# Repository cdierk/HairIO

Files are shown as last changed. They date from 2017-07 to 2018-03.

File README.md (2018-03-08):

# HairIO: Human Hair as interactive Material
Shared Repository for HairIO: Human Hair as interactive Material

# Hardware details
- Microcontroller: Arduino Nano, ordered from AliExpress. Requires [these drivers.](https://github.com/MPParsley/ch340g-ch34g-ch34x-mac-os-x-driver/)
- 

# Circuit diagram for SFCS from Disney's Touche project, as shared by Illutron
// Illutron take on Disney style capacitive touch sensor using only passives and Arduino
// Dzl 2012

```
//                              10n
// PIN 9 --[10k]-+-----10mH---+--||-- OBJECT
//               |            |
//              3.3k          |
//               |            V 1N4148 diode
//              GND           |
//                            |
//Analog 0 ---+------+--------+
//            |      |
//          100pf   1MOmhm
//            |      |
//           GND    GND
```

# Arduino code
- [mux_4052](https://github.com/cdierk/EEPP/tree/master/4052_mux_test_code) - newer version of mux that only requires two pins to select between 4 inputs. Uses [Disney's Touche that was ported to Arduino.](http://www.instructables.com/id/Touche-for-Arduino-Advanced-touch-sensing/)
- [touch_sensing_bluefruit_v2](https://github.com/cdierk/EEPP/tree/master/touch_sensing_bluefruit_v2) - Currently believe this is what's in the bluetooth-enabled demo box w/ brown hair that can actuate and communicate over bluetooth.

# Arduino pinout notes
## For mux_4052 code
- pinMode(9, OUTPUT);       //-Signal generator pin  // digital PWM
- pinMode(8, OUTPUT);       //-Sync (test) pin       // digital
- pinMode(LED, OUTPUT);
- pinMode(muxApin, OUTPUT);                          // pin 6, digital PWM
- pinMode(muxBpin, OUTPUT);                          // pin 5, digital PWM
- pinMode(braidOutput, OUTPUT);                      // pin 2, digital
- // Also uses Analog 0 later.
  
  Total: 5 digital pins, 1 analog pin.
  
## For touch_sensing_bluefruit_v2 code
// cap-sense pin
- pinMode(9, OUTPUT);       //-Signal generator pin
- pinMode(8, OUTPUT);       //-Sync (test) pin
- pinMode(drive, OUTPUT);

 //bluetooth:
- BLUEFRUIT_UART_MODE_PIN,
- BLUEFRUIT_UART_CTS_PIN, 
- BLUEFRUIT_UART_RTS_PIN

# Resources
[Instructable for Disney Touche's SFCS](http://www.instructables.com/id/Touche-for-Arduino-Advanced-touch-sensing/)

# Datasheets and Circuit Info
- [4052 mux from TI](http://www.ti.com/lit/ds/symlink/cd4051b.pdf)
- [Arduino Nano CAD files](https://forum.arduino.cc/index.php?topic=373897.0)
- [SPDT Slide switch datasheet from DigiKey](https://media.digikey.com/pdf/Data%20Sheets/C&K/SS-12D07-VG_GA_PA.pdf)
  - For Eagle, use a 1x3-pin header from Pinhead since they are also 2mm apart.

# demo
- Multiple braids w/ BLE
- Single braid w/ BLE

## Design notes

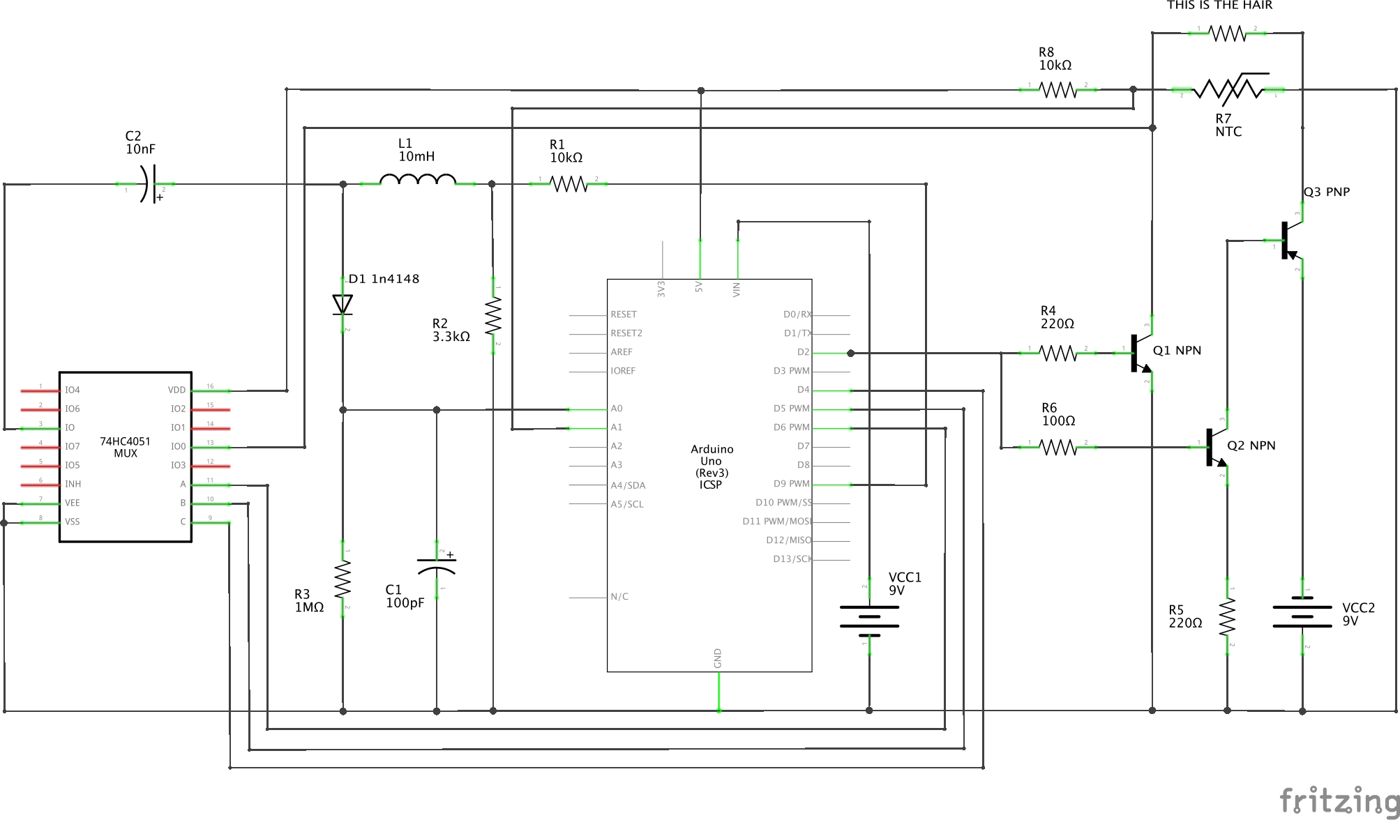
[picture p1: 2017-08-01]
hair_whole_system_schem.png

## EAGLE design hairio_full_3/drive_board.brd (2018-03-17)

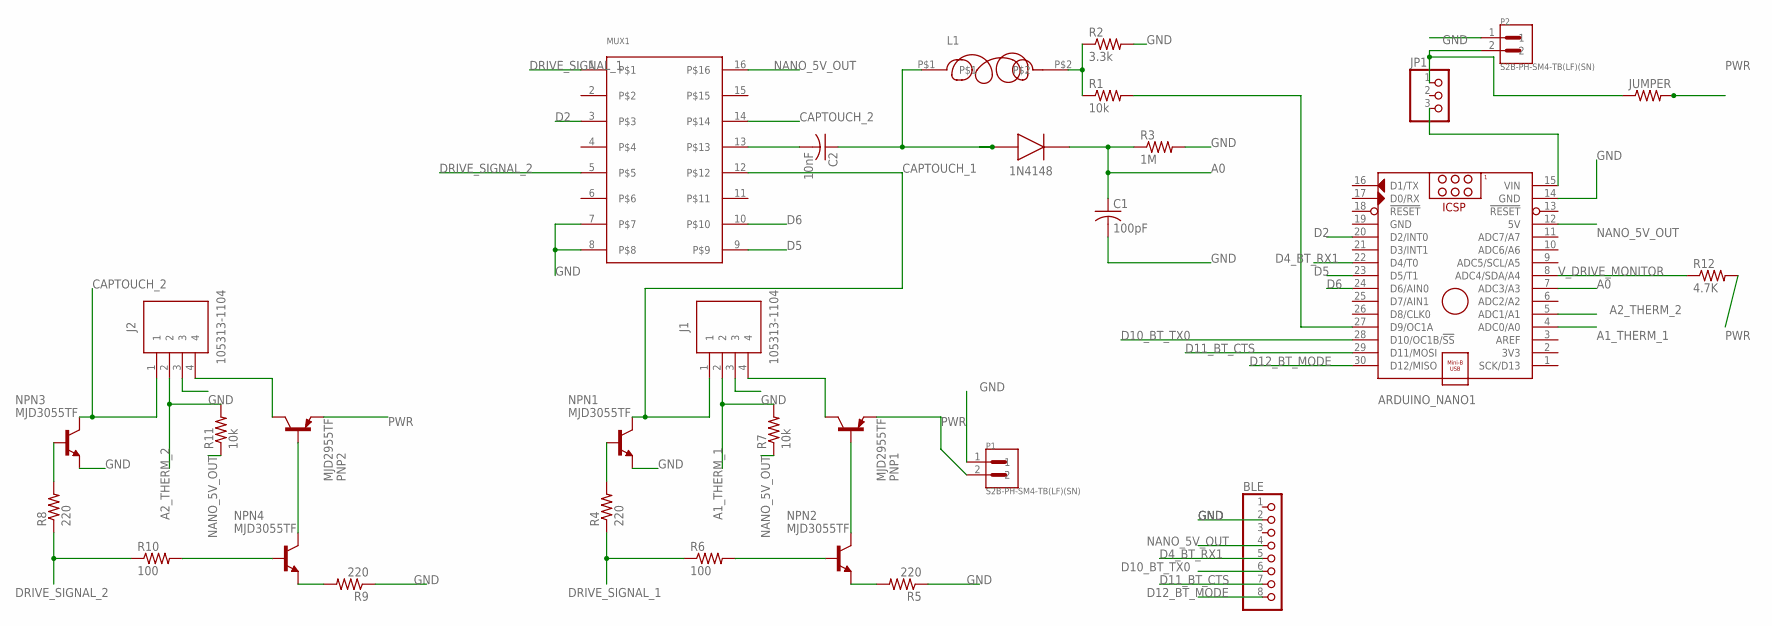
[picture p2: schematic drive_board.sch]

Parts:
1N4148: 1N5819HW-7-F; SOD3716X145N
ARDUINO_NANO1: ARDUINO_NANO
BLE: PINHD-1X8; 1X08
C1: 100pF; C0805
C2: 10nF; C0805
J1, J2: 105313-1104
JP1: PINHD-1X3; 1X03
JUMPER: R-US_R0805; R0805
L1: SRE6603
MUX1: HAIRIO_MUX; SO16
NPN1, NPN2, NPN3, NPN4: MJD3055TF; DPAK
P1, P2: S2B-PH-SM4-TB(LF)(SN); JST_S2B-PH-SM4-TB(LF)(SN)
PNP1, PNP2: MJD2955TF; DPAK
R1, R7, R11: 10k; R0805
R2: 3.3k; R0805
R3: 1M; R0805
R4, R5, R8, R9: 220; R0805
R6, R10: 100; R0805
R12: 4.7K; R0805

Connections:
A0: 1N4148.1 (K), ARDUINO_NANO1.7 (ADC3/A3), C1.1, R3.1
A1_THERM_1: ARDUINO_NANO1.4 (ADC0/A0), J1.2, R7.2
A2_THERM_2: ARDUINO_NANO1.5 (ADC1/A1), J2.2, R11.2
CAPTOUCH_1: J1.1, MUX1.12, NPN1.4 (C)
CAPTOUCH_2: J2.1, MUX1.14, NPN3.4 (C)
D2: ARDUINO_NANO1.20 (D2/INT0), MUX1.3
D4_BT_RX1: ARDUINO_NANO1.22 (D4/T0), BLE.5
D5: ARDUINO_NANO1.23 (D5/T1), MUX1.9
D6: ARDUINO_NANO1.24 (D6/AIN0), MUX1.10
D10_BT_TX0: ARDUINO_NANO1.28 (D10/OC1B/!SS), BLE.6
D11_BT_CTS: ARDUINO_NANO1.29 (D11/MOSI), BLE.7
D12_BT_MODE: ARDUINO_NANO1.30 (D12/MISO), BLE.8
DRIVE_SIGNAL_1: MUX1.1, R4.1, R6.1
DRIVE_SIGNAL_2: MUX1.5, R8.1, R10.1
GND: ARDUINO_NANO1.14 (GND), ARDUINO_NANO1.19 (GND), BLE.2, C1.2, J1.3, J2.3, MUX1.7, MUX1.8, NPN1.3 (E), NPN3.3 (E), P1.1, P2.1, R2.2, R3.2, R5.1, R9.1
unnamed: NPN2.1 (B), R6.2
unnamed: NPN2.3 (E), R5.2
unnamed: NPN4.1 (B), R10.2
unnamed: NPN2.4 (C), PNP1.1 (B)
unnamed: NPN1.1 (B), R4.2
unnamed: C2.2, MUX1.13
unnamed: 1N4148.2 (A), C2.1, L1.P$1
unnamed: J1.4, PNP1.4 (C)
unnamed: ARDUINO_NANO1.27 (D9/OC1A), R1.2
unnamed: L1.P$2, R1.1, R2.1
unnamed: NPN4.3 (E), R9.2
unnamed: ARDUINO_NANO1.15 (VIN), JP1.3
unnamed: NPN4.4 (C), PNP2.1 (B)
unnamed: NPN3.1 (B), R8.2
unnamed: J2.4, PNP2.4 (C)
unnamed: JP1.1, JUMPER.1, P2.2
NANO_5V_OUT: ARDUINO_NANO1.12 (5V), BLE.4, MUX1.16, R7.1, R11.1
PWR: JUMPER.2, P1.2, PNP1.3 (E), PNP2.3 (E), R12.2
V_DRIVE_MONITOR: ARDUINO_NANO1.8 (ADC4/SDA/A4), R12.1

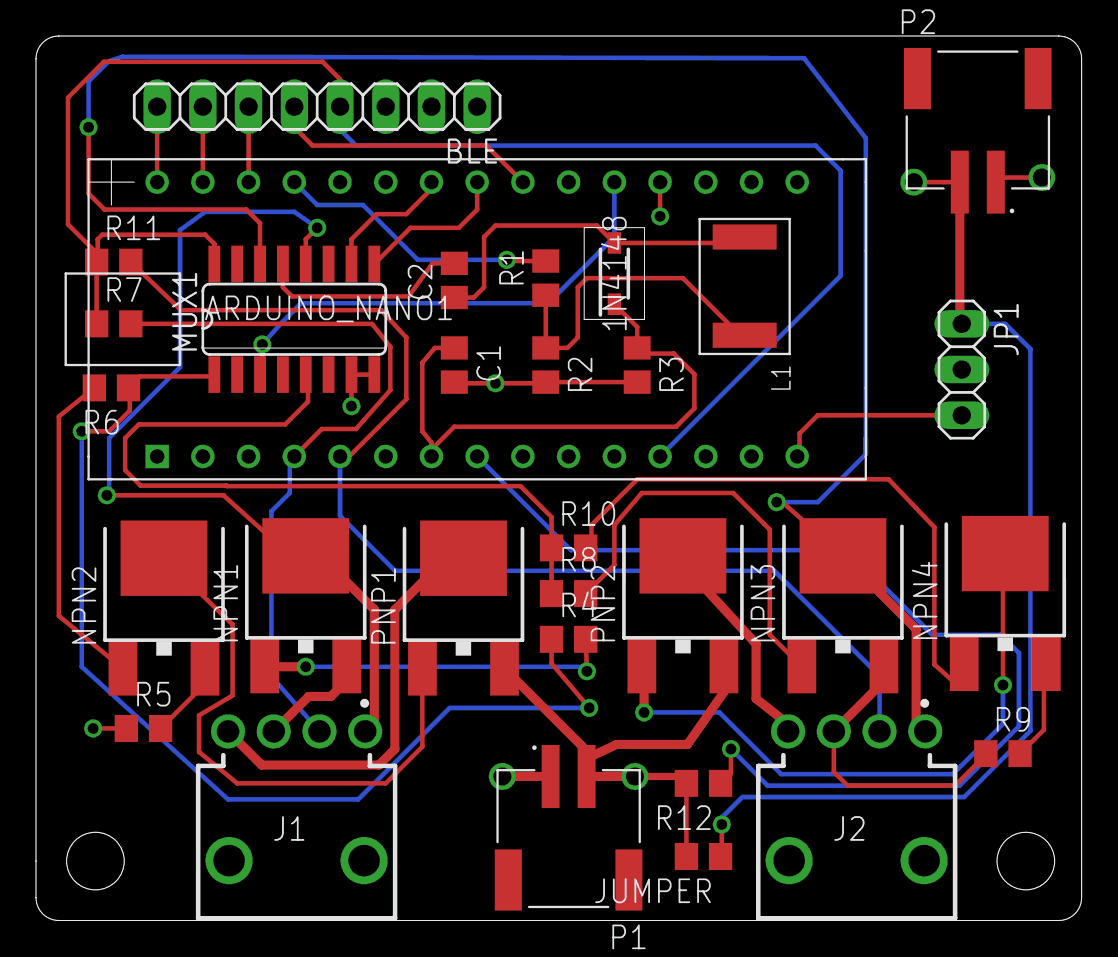
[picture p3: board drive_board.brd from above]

Board: 2 copper layers, 58.1 x 49.1 mm, 31 parts (0 on the bottom side), 34 nets.

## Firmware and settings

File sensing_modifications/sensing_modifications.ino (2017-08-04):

//****************************************************************************************
// Adapted from https://github.com/Illutron/AdvancedTouchSensing
// Moves the gesture analysis from Processing to run entirely on Arduino, with fixed thresholds
// July 21 2017
//****************************************************************************************



//****************************************************************************************
// Illutron take on Disney style capacitive touch sensor using only passives and Arduino
// Dzl 2012
//****************************************************************************************


//                              10n
// PIN 9 --[10k]-+-----10mH---+--||-- OBJECT
//               |            |
//              3.3k          |
//               |            V 1N4148 diode
//              GND           |
//                            |
//Analog 0 ---+------+--------+
//            |      |
//          100pf   1MOmhm
//            |      |
//           GND    GND

//EDIT THIS ONE YAY!
float tempThreshhold = 32.0;

#define SET(x,y) (x |=(1<<y))        //-Bit set/clear macros
#define CLR(x,y) (x &= (~(1<<y)))           // |
#define CHK(x,y) (x & (1<<y))               // |
#define TOG(x,y) (x^=(1<<y))                //-+

#define LED 13 // LED for serial-less debugging.

#define N 160  //How many frequencies

//mux
#define muxApin 6
#define muxBpin 5
#define muxCpin 4
int previousMillis = 0;
#define switchInterval 100

unsigned int currentMillis = 0;

#define braid0 2    //pin for braid 0 output
#define braid1 3    //pin for braid 1 output
#define braid2 7    //pin for braid 2 output

//thermistor specific stuff
#define therm0 A1   //pin for braid 0 thermistor
#define therm1 A2   //pin for braid 1 thermistor
#define therm2 A3   //pin for braid 2 thermistor
//resistance at 25 degrees C
#define THERMISTORNOMINAL 10000
// temperature for nominal resistance
#define TEMPERATURENOMINAL 25
//how many samples to take before averaging the temperature
#define NUMSAMPLES 5
//beta coefficient of the thermistor
#define BCOEFFICIENT 3950
//value of 'other' resistor
#define SERIESRESISTOR 10000


int on_average = 0;
int off_average = 0;

int on_average_count = 0;
int off_average_count = 0;

int currentBraid = braid0;
int currentTherm = therm0;

uint16_t samples[NUMSAMPLES];

bool driving = false; //true if currently driving one of the braids

//Gesture sensing variables
float results[N];            //-Filtered result buffer
float freq[N];            //-Filtered result buffer
int sizeOfArray = N;

//Gesture processing variables
float gesturePoints[2][2];
float gestureDist[2];
String names[2] = {"nothing", "touch"};

int curGesture = 0;
int lastGesture = 0;

void setGestureThresholds() {
  gesturePoints[0][0] = 0;
  gesturePoints[0][1] = 350;

  gesturePoints[1][0] = 0;
  gesturePoints[1][1] = 310;

  on_average = gesturePoints[1][1];
  off_average = gesturePoints[0][1];
  
  on_average_count = 1;
  off_average_count = 1;

}


void setup()
{

  Serial.begin(115200);
  Serial.println("STart");
  
  TCCR1A = 0b10000010;      //-Set up frequency generator
  TCCR1B = 0b00011001;      //-+
  ICR1 = 110;
  OCR1A = 55;

  pinMode(9, OUTPUT);       //-Signal generator pin
  pinMode(8, OUTPUT);       //-Sync (test) pin
  pinMode(LED, OUTPUT);
  pinMode(muxApin, OUTPUT);
  pinMode(muxBpin, OUTPUT);
  pinMode(muxCpin, OUTPUT);
  pinMode(braid0, OUTPUT);
  pinMode(braid1, OUTPUT);
  pinMode(braid2, OUTPUT);
  pinMode(10, INPUT);         //config
  pinMode(12, INPUT);         //config
  pinMode(13, OUTPUT);       //LED

  // initialize results array to all zeros
  memset(results,0,sizeof(results)); 

  driving= false;

    digitalWrite(muxApin, 0);
    digitalWrite(muxBpin, 0);
    digitalWrite(muxCpin, 0);

  setGestureThresholds();

}




void processGesture() {
  //input found on current braid
  if ((curGesture == 1) && (currentMillis > 5000)){
//    digitalWrite(currentBraid, HIGH);
    digitalWrite(13, HIGH);
//    driving = true;
  } else {
     digitalWrite(13, LOW);
  }
}

//adapted from http://forum.arduino.cc/index.php?topic=41999.0
float getMaxFromArray(float* array, int size) {
  float max = array[0];
  for (int i = 1; i < size; i++) {
    if (max < array[i]) {
      max = array[i];
    }
  }
  return max;
}

int getMaxIndexFromArray(float* array, int size) {
  float max = array[0];
  int index = 0;
  for (int i = 1; i < size; i++) {
    if (max < array[i]) {
      max = array[i];
      index = i;
    }
  }
  return index;
}

//assumes no negative values for time or voltage
float dist(float x1, float y1, float x2, float y2) {
  float xmax = max(x1, x2);
  float ymax = max(y1, y2);

  float w;
  if (x1 > x2) {
    w = x1 - x2;
  } else {
    w = x2 - x1;
  }
  float h;
  if (y1 > y2) {
    h = y1 - y2;
  } else {
    h = y2 - y1;
  }

  return sqrt(h * h + w * w);
}

void analyzeInput(float timeArr[], float voltageArr[]) {

  /* ====================================================================
    Gesture compare
    ====================================================================  */
  
    int currentMax = 0;
    float currentMaxValue = -1;
    for (int i = 0; i < 2; i++)
    {
      //calculate individual dist
      gestureDist[i] = dist(getMaxFromArray(timeArr, N), getMaxFromArray(voltageArr, N), gesturePoints[i][0], gesturePoints[i][1]);
  
      if (gestureDist[i] < currentMaxValue || i == 0)
      {
        currentMax = i;
        currentMaxValue =  gestureDist[i];
      }
    }
  
    int type = currentMax;
    lastGesture = curGesture;
    curGesture = type;

}

void update_thresholds(float freq[], float volts[], char type) {
    Serial.println("old threshold:");
    Serial.println(type);
    Serial.println(gesturePoints[0][0]);
    Serial.println(gesturePoints[0][1]);
    Serial.println(gesturePoints[1][0]);
    Serial.println(gesturePoints[1][1]);

    float on_average = 0;
    float off_average = 0;
    float on_freq = 0;
    float off_freq = 0;

    for (int i = 0; i < 100; i++) {
              unsigned int d;
            
              int counter = 0;
              for (unsigned int d = 0; d < N; d++) {
                int v = analogRead(0);  //-Read response signal
                CLR(TCCR1B, 0);         //-Stop generator
                TCNT1 = 0;              //-Reload new frequency
                ICR1 = d;               // |
                OCR1A = d / 2;          //-+
                SET(TCCR1B, 0);         //-Restart generator
            
                results[d] = results[d] * 0.5 + (float)(v) * 0.5; //Filter results
                   
                freq[d] = d;
            
                //   plot(v,0);              //-Display
                //   plot(results[d],1);
                 delayMicroseconds(10);
              }
         if (type == 't') {
           on_average += getMaxFromArray(results, N);
//           on_freq += freq[getMaxIndexFromArray(results, N)];
         } else if (type == 'n'){
           off_average = off_average + ( getMaxFromArray(results, N) ) / off_average_count;
//           off_freq += freq[getMaxIndexFromArray(results, N);

         }
    }

    if (type == 't') {
      on_average = on_average / 100;
      on_freq = on_freq / 100;
      gesturePoints[1][0] = on_freq;
      gesturePoints[1][1] = on_average;
    } else if (type == 'n') {
      off_average = off_average/100;
      off_freq = off_freq/100;

      gesturePoints[0][0] = off_freq;
      gesturePoints[0][1] = off_average;
    }

    Serial.println("new threshold:");
    Serial.println(gesturePoints[0][0]);
    Serial.println(gesturePoints[0][1]);
    Serial.println(gesturePoints[1][0]);
    Serial.println(gesturePoints[1][1]);
    
//    if (type == 't') {

//      on_average = on_average + ( getMaxFromArray(volts, N) ) / on_average_count;
//      on_average_count = on_average_count + 1;
//            
//      gesturePoints[1][0] = getMaxIndexFromArray(volts, N);
//      gesturePoints[1][1] = on_average;
//    } else if (type == 'n'){
//
//      off_average = off_average + ( getMaxFromArray(volts, N) ) / off_average_count;
//      off_average_count = off_average_count + 1;
//
//      gesturePoints[0][0] = getMaxIndexFromArray(volts, N);
//      gesturePoints[0][1] = off_average;
//    }  
}

void loop()
{
              unsigned int d;
            
              int counter = 0;
              for (unsigned int d = 0; d < N; d++) {
                int v = analogRead(0);  //-Read response signal
                CLR(TCCR1B, 0);         //-Stop generator
                TCNT1 = 0;              //-Reload new frequency
                ICR1 = d;               // |
                OCR1A = d / 2;          //-+
                SET(TCCR1B, 0);         //-Restart generator
            
                results[d] = results[d] * 0.5 + (float)(v) * 0.5; //Filter results
                   
                freq[d] = d;
            
                //   plot(v,0);              //-Display
                //   plot(results[d],1);
                // delayMicroseconds(1);
              }


  //this would send the data to processing
//  PlottArray(1,freq,results);

  // instead of sending to processing, do the work here

  
  analyzeInput(freq, results);


  processGesture();

  if (digitalRead(12) == HIGH) {
    update_thresholds(freq, results, 't'); 
  } else if (digitalRead(10) == HIGH) {
    update_thresholds(freq, results, 'n');
  }

    //mux -- cycles through braids looking for input
    currentMillis = millis();
                                            
                                        //    //doesn't cycle if powering one of the braids
                                        //    if((currentMillis - previousMillis > switchInterval) && (driving == false)){
                                        //      // save the last time you switched 
                                        //      previousMillis = currentMillis;   
                                        //
                                              if (currentBraid == braid0){               //mux pin0 is attached to same braid as Arduino pin2
                                                digitalWrite(muxApin, 0);
                                                digitalWrite(muxBpin, 0);
                                                digitalWrite(muxCpin, 0);
                                                currentBraid = braid0;  
                                              }
                                               //UNCOMMENT THIS FOR MULTI-BRAID USE!
                                        //      } else if (currentBraid == braid1){        //mux pin1 is attached to same braid as Arduino pin3
                                        //        digitalWrite(muxApin, 1);
                                        //        digitalWrite(muxBpin, 0);
                                        //        digitalWrite(muxCpin, 0);
                                        //        currentBraid = braid0;
                                        //      }
                                        //      } else {        //mux pin2 is attached to same braid as Arduino pin7
                                        //        digitalWrite(muxApin, 0);
                                        //        digitalWrite(muxBpin, 1);
                                        //        digitalWrite(muxCpin, 0);
                                        //        currentBraid = braid0;
                                        //      }
                                        //    }

    
    //only care about thermistor values if we're currently driving
      if (driving == true) {
                                                                                uint8_t i;
                                                                                float average;
                                                                        
                                                                                //take N samples in a row, with a slight delay
                                                                                if (currentBraid == braid0) currentTherm = therm0;
                                                                                else if (currentBraid == braid1) currentTherm = therm1;
                                                                                else if (currentBraid == braid2) currentTherm = therm2;
                                                                                
                                                                                for (i = 0; i < NUMSAMPLES; i++) {
                                                                                  samples[i] = analogRead(currentTherm);
                                                                                  delay(10);
                                                                                }
                                                                        
                                                                                // average all the samples out
                                                                                average = 0;
                                                                                for (i = 0; i < NUMSAMPLES; i++) {
                                                                                  average += samples[i];
                                                                                }
                                                                                average /= NUMSAMPLES;
                                                                        
                                                                                //convert these values to resistance
                                                                                average = 1023 / average - 1;
                                                                                average = SERIESRESISTOR / average;
                                                                        
                                                                                //convert these values to temperature
                                                                                average = average / THERMISTORNOMINAL;
                                                                                average = log(average);
                                                                                average /= BCOEFFICIENT;
                                                                                average += 1.0 / (TEMPERATURENOMINAL + 273.15);
                                                                                average = 1.0 / average;
                                                                                average -= 273.15;
                                                                        
                                                                                //average is now the temperature of the thermistor
                                                                        //        Serial.println(average);
                                                                        
                                                                                if ( average <= 0.0){
                                                                                  digitalWrite(currentBraid, LOW);
                                                                                  driving = false;
                                                                                  delay(5000);
                                                                                  
                                                                                } else if (average >= tempThreshhold){
                                                                        //          Serial.println("here inside kill");
                                                                                  digitalWrite(currentBraid, LOW);
                                                                                  driving = false;
                                                                                }
        
      }

  TOG(PORTB, 0);           //-Toggle pin 8 after each sweep (good for scope)
}

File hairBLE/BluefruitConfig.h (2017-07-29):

// COMMON SETTINGS
// ----------------------------------------------------------------------------------------------
// These settings are used in both SW UART, HW UART and SPI mode
// ----------------------------------------------------------------------------------------------
#define BUFSIZE                        128   // Size of the read buffer for incoming data
#define VERBOSE_MODE                   true  // If set to 'true' enables debug output


// SOFTWARE UART SETTINGS
// ----------------------------------------------------------------------------------------------
// The following macros declare the pins that will be used for 'SW' serial.
// You should use this option if you are connecting the UART Friend to an UNO
// ----------------------------------------------------------------------------------------------
#define BLUEFRUIT_SWUART_RXD_PIN       5    // Required for software serial!
#define BLUEFRUIT_SWUART_TXD_PIN       10   // Required for software serial!
#define BLUEFRUIT_UART_CTS_PIN         11   // Required for software serial!
#define BLUEFRUIT_UART_RTS_PIN         -1   // Optional, set to -1 if unused


// HARDWARE UART SETTINGS
// ----------------------------------------------------------------------------------------------
// The following macros declare the HW serial port you are using. Uncomment
// this line if you are connecting the BLE to Leonardo/Micro or Flora
// ----------------------------------------------------------------------------------------------
#ifdef Serial1    // this makes it not complain on compilation if there's no Serial1
  #define BLUEFRUIT_HWSERIAL_NAME      Serial1
#endif


// SHARED UART SETTINGS
// ----------------------------------------------------------------------------------------------
// The following sets the optional Mode pin, its recommended but not required
// ----------------------------------------------------------------------------------------------
#define BLUEFRUIT_UART_MODE_PIN        12    // Set to -1 if unused


// SHARED SPI SETTINGS
// ----------------------------------------------------------------------------------------------
// The following macros declare the pins to use for HW and SW SPI communication.
// SCK, MISO and MOSI should be connected to the HW SPI pins on the Uno when
// using HW SPI.  This should be used with nRF51822 based Bluefruit LE modules
// that use SPI (Bluefruit LE SPI Friend).
// ----------------------------------------------------------------------------------------------
#define BLUEFRUIT_SPI_CS               8
#define BLUEFRUIT_SPI_IRQ              7
#define BLUEFRUIT_SPI_RST              4    // Optional but recommended, set to -1 if unused

// SOFTWARE SPI SETTINGS
// ----------------------------------------------------------------------------------------------
// The following macros declare the pins to use for SW SPI communication.
// This should be used with nRF51822 based Bluefruit LE modules that use SPI
// (Bluefruit LE SPI Friend).
// ----------------------------------------------------------------------------------------------
#define BLUEFRUIT_SPI_SCK              13
#define BLUEFRUIT_SPI_MISO             12
#define BLUEFRUIT_SPI_MOSI             11

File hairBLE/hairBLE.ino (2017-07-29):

/*********************************************************************
 This is an example for our nRF51822 based Bluefruit LE modules

 Pick one up today in the adafruit shop!

 Adafruit invests time and resources providing this open source code,
 please support Adafruit and open-source hardware by purchasing
 products from Adafruit!

 MIT license, check LICENSE for more information
 All text above, and the splash screen below must be included in
 any redistribution
*********************************************************************/

#include <Arduino.h>
#include <SPI.h>
#if not defined (_VARIANT_ARDUINO_DUE_X_) && not defined (_VARIANT_ARDUINO_ZERO_)
  #include <SoftwareSerial.h>
#endif

#include "Adafruit_BLE.h"
#include "Adafruit_BluefruitLE_UART.h"

#include "BluefruitConfig.h"

/*=========================================================================
    APPLICATION SETTINGS

    FACTORYRESET_ENABLE       Perform a factory reset when running this sketch
   
                              Enabling this will put your Bluefruit LE module
                              in a 'known good' state and clear any config
                              data set in previous sketches or projects, so
                              running this at least once is a good idea.
   
                              When deploying your project, however, you will
                              want to disable factory reset by setting this
                              value to 0.  If you are making changes to your
                              Bluefruit LE device via AT commands, and those
                              changes aren't persisting across resets, this
                              is the reason why.  Factory reset will erase
                              the non-volatile memory where config data is
                              stored, setting it back to factory default
                              values.
       
                              Some sketches that require you to bond to a
                              central device (HID mouse, keyboard, etc.)
                              won't work at all with this feature enabled
                              since the factory reset will clear all of the
                              bonding data stored on the chip, meaning the
                              central device won't be able to reconnect.
    MINIMUM_FIRMWARE_VERSION  Minimum firmware version to have some new features
    MODE_LED_BEHAVIOUR        LED activity, valid options are
                              "DISABLE" or "MODE" or "BLEUART" or
                              "HWUART"  or "SPI"  or "MANUAL"
    -----------------------------------------------------------------------*/
    #define FACTORYRESET_ENABLE         1
    #define MINIMUM_FIRMWARE_VERSION    "0.6.6"
    #define MODE_LED_BEHAVIOUR          "MODE"
/*=========================================================================*/

// Create the bluefruit object in software serial

SoftwareSerial bluefruitSS = SoftwareSerial(BLUEFRUIT_SWUART_TXD_PIN, BLUEFRUIT_SWUART_RXD_PIN);

Adafruit_BluefruitLE_UART ble(bluefruitSS, BLUEFRUIT_UART_MODE_PIN,
                      BLUEFRUIT_UART_CTS_PIN, BLUEFRUIT_UART_RTS_PIN);


// A small helper
void error(const __FlashStringHelper*err) {
  Serial.println(err);
  while (1);
}

/**************************************************************************/
/*!
    @brief  Sets up the HW an the BLE module (this function is called
            automatically on startup)
*/
/**************************************************************************/
void setup(void)
{
  while (!Serial);  // required for Flora & Micro
  delay(500);

  Serial.begin(115200);
  Serial.println(F("Adafruit Bluefruit Command <-> Data Mode Example"));
  Serial.println(F("------------------------------------------------"));

  /* Initialise the module */
  Serial.print(F("Initialising the Bluefruit LE module: "));

  if ( !ble.begin(VERBOSE_MODE) )
  {
    error(F("Couldn't find Bluefruit, make sure it's in CoMmanD mode & check wiring?"));
  }
  Serial.println( F("OK!") );

  if ( FACTORYRESET_ENABLE )
  {
    /* Perform a factory reset to make sure everything is in a known state */
    Serial.println(F("Performing a factory reset: "));
    if ( ! ble.factoryReset() ){
      error(F("Couldn't factory reset"));
    }
  }

  /* Disable command echo from Bluefruit */
  ble.echo(false);

  Serial.println("Requesting Bluefruit info:");
  /* Print Bluefruit information */
  ble.info();

  Serial.println(F("Please use Adafruit Bluefruit LE app to connect in UART mode"));
  Serial.println(F("Then Enter characters to send to Bluefruit"));
  Serial.println();

  ble.verbose(false);  // debug info is a little annoying after this point!

  /* Wait for connection */
  while (! ble.isConnected()) {
      delay(500);
  }

  Serial.println(F("******************************"));

  // LED Activity command is only supported from 0.6.6
  if ( ble.isVersionAtLeast(MINIMUM_FIRMWARE_VERSION) )
  {
    // Change Mode LED Activity
    Serial.println(F("Change LED activity to " MODE_LED_BEHAVIOUR));
    ble.sendCommandCheckOK("AT+HWModeLED=" MODE_LED_BEHAVIOUR);
  }

  // Set module to DATA mode
  Serial.println( F("Switching to DATA mode!") );
  ble.setMode(BLUEFRUIT_MODE_DATA);

  Serial.println(F("******************************"));
}

/**************************************************************************/
/*!
    @brief  Constantly poll for new command or response data
*/
/**************************************************************************/
void loop(void)
{
  // Check for user input
  char n, inputs[BUFSIZE+1];

  if (Serial.available())
  {
    n = Serial.readBytes(inputs, BUFSIZE);
    inputs[n] = 0;
    // Send characters to Bluefruit
    Serial.print("Sending: ");
    Serial.println(inputs);

    // Send input data to host via Bluefruit
    ble.print(inputs);
  }

  // Echo received data
  while ( ble.available() )
  {
    int c = ble.read();

    Serial.print((char)c);

    // Hex output too, helps w/debugging!
    Serial.print(" [0x");
    if (c <= 0xF) Serial.print(F("0"));
    Serial.print(c, HEX);
    Serial.print("] ");
  }
}

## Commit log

2017-07-21 arduino code for touch sensing
2017-07-21 Add first draft of hair curling, color-changing arduino code
2017-07-21 Update for circuit testing - pin 3 goes high and pin 4 goes low.
2017-07-26 Edited Arduino_sensing file to include multiplexer use
    added lines have //mux notes above them. Use with Illutron processing script to visualize. At present, cycles between two capacitive touch inputs at a rate of 5000ms (5 seconds).
2017-07-28 Basic BLE UART from hair circuit to iOS
2017-07-28 Full integrated system (input, output, bluetooth)
    Using mpr121 & bluefruit. Drive circuit is written high from Arduino pin 4.
    Does not include thermistor or multiplexor.
2017-07-29 Tidied up code and switched to LED signal instead of serial print to save bytes
2017-07-29 Updated touch_sensing file with multiplexer code
    Supports 4 braid input with one capacitive touch shield
2017-07-29 Debug messages.
    These confirm that the values passed into the "dist" method
    in arrays don't need to be floats - they are all of the form 158.00
    with no values ever below one. The sqrt value does end up
    having some decimal values: 172.36, but the behavior of the circuit
    seems to be just as good if we use just the int portion of those values
    (dropping the decimal values by storing it in an int instead.)
2017-07-29 Remove some debug prints
2017-07-29 CapSensing Board + Bluefruit
    Currently writing high to pin 13 (Arduino built-in LED) rather than drive circuit. If we change this pin to a pin connected to drive circuit, everything should work!
2017-07-31 multiplexer integration with thermistor, drive, and cap; checks to limit captouch during drive; drive and thermister shut off
2017-08-01 Circuit Diagram excluding BlueTooth
    Includes everything else: cap touch circuit, driver circuit, thermistor, arduino, batteries
    [hair_whole_system.fzz]
2017-08-01 Circuit Diagram excluding BlueTooth
    Includes everything else: cap touch circuit, driver circuit, thermistor, batteries.
    Right now has a resistor as a stand in for the hair and says "this is the hair". Planning to doctor the image in Adobe Illustrator to include an illustrated braid. Also going to outline the different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
2017-08-02 Power test 1 and 2
    temperature and timing for color and shape changes (when they begin and when they finish)
    Power_test_one didn't mark anything past color end and runs for a long time (we were trying to get it to change all the way before realizing that was unfeasible).
2017-08-02 Power Test 3: 1.0A, 1.7V
2017-08-02 Power tests 4 and 5: 3.25V, 2A
2017-08-02 Power Test 6: 3.3V 2A
2017-08-04 demo code
    [power_data.xlsx, power_test_2.csv, power_test_3.csv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]
2018-01-23 rename because arduino IDE didn't like the file starting with a number
    [mux_4052.ino]
2018-02-03 demo board eagle files
    [drive_board.brd, drive_board.sch]
2018-02-06 updated board files
    [drive_board.brd]
2018-02-06 updated net class clearance
    [drive_board.brd, drive_board.sch]
2018-02-08 Updated Capacitive Touch Pin to A5 (from A0)
    also added this as a global variable (capTouchPin) so that we can easily update it in the future
2018-02-08 update board
    [drive_board.brd, drive_board.sch]
2018-02-08 hairio board with no routes between header pins
    [drive_board.brd]
2018-02-08 change via size and shift trace
    [drive_board.brd]
2018-02-08 More tweaks to board
    [drive_board.brd]
2018-02-13 added basic mux
    updated pin numbers in BluefruitConfig.h as well
2018-02-23 added thermistor code and braidx struct; reorganized variables. Untested.
2018-02-23 battery monitoring code, still untested
2018-02-24 working demo code with voltage monitoring for both batteries and thermistor logging
2018-03-02 new board -- the dimensioned version of what got made for demos (with ground plane fix after accidental deletion)
    [drive_board.brd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]
2018-03-08 board layout with dimensions -- modified post fabrication
    [drive_board.brd]
2018-03-12 updating demo code for two braids and captouch calibration; untested
2018-03-12 added bluetooth writes to calibration and fixed EEPROM byte reads/writes
